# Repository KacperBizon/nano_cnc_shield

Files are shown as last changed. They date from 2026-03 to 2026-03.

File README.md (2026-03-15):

# Arduino Nano CNC shield
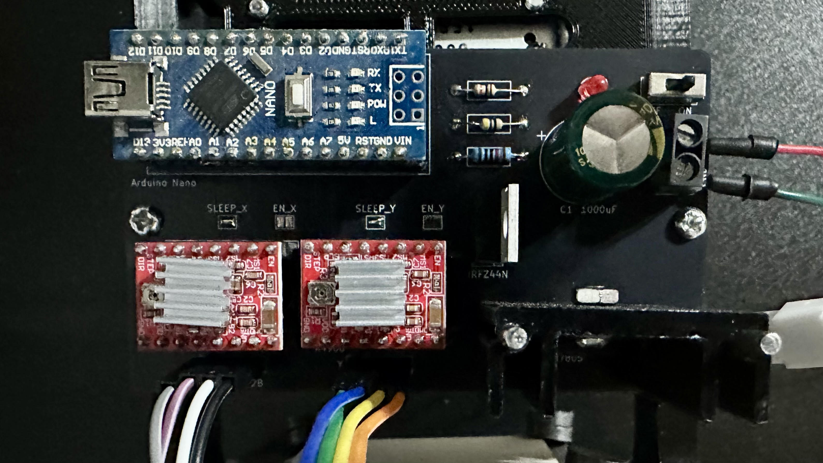
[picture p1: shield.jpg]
pcb image


### How to use
- Install [LaserGRBL](https://github.com/arkypita/LaserGRBL/releases)
- Upload [GRBL](https://github.com/gnea/grbl) code to Arduino 

### Components
* Arduino Nano
* 2x A4988 Stepper motor drivers
* 1x IRFZ44N N-CHANNEL MOSFET
* 1x LM7805 Voltage regulator with Heatsink (note the regulator is now rotated on the PCB)
* 1x 47, 1x 1k and 1x 10k resistor
* 3mm diode
* slide switch (SS12D00)
* 1x 1000uF 16V capacitor or 2x 100uF capacitors
* 1x 2.5mm JST XH-Style 2pin male connector
* male and female header pins

### Acknowledgments
The project is based on [DIY-Mini-CNC-Laser-Engraver](https://www.instructables.com/DIY-Mini-CNC-Laser-Engraver/)

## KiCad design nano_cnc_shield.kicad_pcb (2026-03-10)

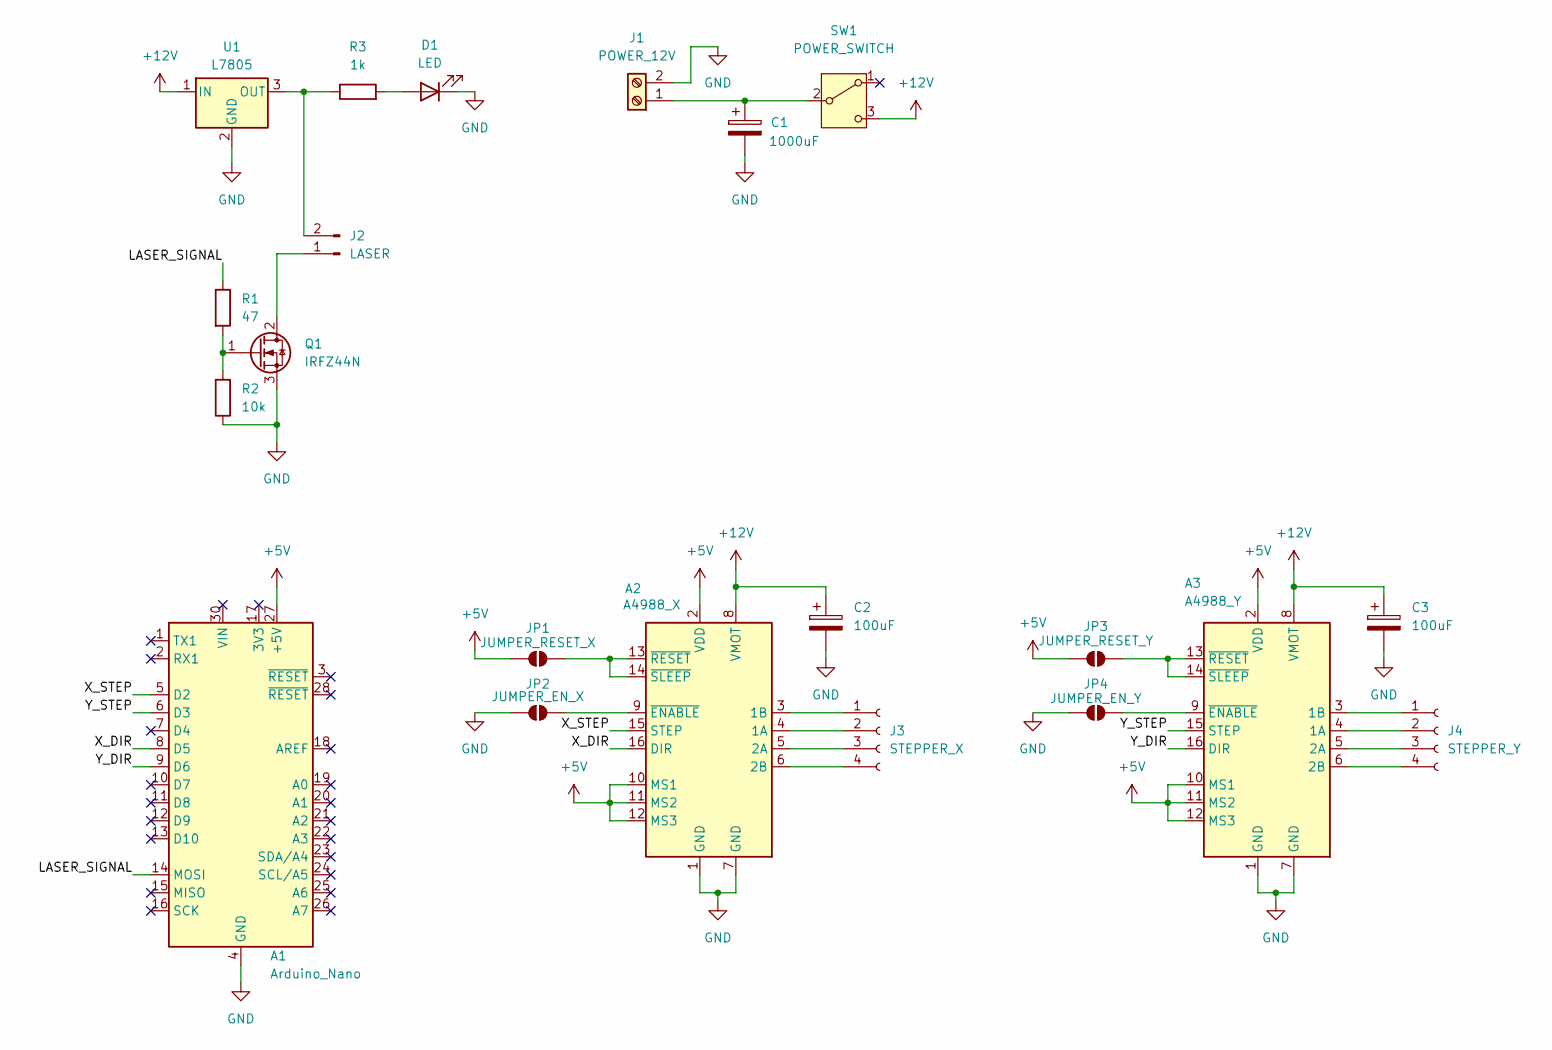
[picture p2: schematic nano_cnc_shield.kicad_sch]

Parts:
A1: Arduino_Nano
A2: A4988_X; Pololu_Breakout-16_15.2x20.3mm
A3: A4988_Y; Pololu_Breakout-16_15.2x20.3mm
C1: 1000uF; CP_Radial_D13.0mm_P5.00mm
C2, C3: 100uF; CP_Radial_D8.0mm_P3.50mm
D1: LED; LED_D3.0mm
J1: POWER_12V; TerminalBlock_RND_205-00045_1x02_P5.00mm_Horizontal
J2: LASER; PinSocket_1x02_P2.54mm_Vertical
J3: STEPPER_X; PinSocket_1x04_P2.54mm_Vertical
J4: STEPPER_Y; PinSocket_1x04_P2.54mm_Vertical
JP1: JUMPER_RESET_X; SolderJumper-2_P1.3mm_Open_Pad1.0x1.5mm
JP2: JUMPER_EN_X; SolderJumper-2_P1.3mm_Open_Pad1.0x1.5mm
JP3: JUMPER_RESET_Y; SolderJumper-2_P1.3mm_Open_Pad1.0x1.5mm
JP4: JUMPER_EN_Y; SolderJumper-2_P1.3mm_Open_Pad1.0x1.5mm
Q1: IRFZ44N; TO-220-3_Vertical
R1: 47; R_Axial_DIN0207_L6.3mm_D2.5mm_P10.16mm_Horizontal
R2: 10k; R_Axial_DIN0207_L6.3mm_D2.5mm_P10.16mm_Horizontal
R3: 1k; R_Axial_DIN0207_L6.3mm_D2.5mm_P10.16mm_Horizontal
SW1: POWER_SWITCH; SW_Slide-03_SS22T35_8.4x3.8x6.8_P2.54mm
U1: L7805; TO-220F-3_Vertical

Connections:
+5V: A1.27 (+5V), A2.2 (VDD), A2.10 (MS1), A2.11 (MS2), A2.12 (MS3), A3.2 (VDD), A3.10 (MS1), A3.11 (MS2), A3.12 (MS3), JP1.1 (A), JP3.1 (A)
+12V: A2.8 (VMOT), A3.8 (VMOT), C2.1, C3.1, SW1.3 (C), U1.1 (IN)
/LASER_SIGNAL: A1.14 (MOSI), R1.1
/X_DIR: A1.8 (D5), A2.16 (DIR)
/X_STEP: A1.5 (D2), A2.15 (STEP)
/Y_DIR: A1.9 (D6), A3.16 (DIR)
/Y_STEP: A1.6 (D3), A3.15 (STEP)
GND: A1.4 (GND), A1.29 (GND), A2.1 (GND), A2.7 (GND), A3.1 (GND), A3.7 (GND), C1.2, C2.2, C3.2, D1.1 (K), J1.2 (GND), JP2.1 (A), JP4.1 (A), Q1.3 (S), R2.1, U1.2 (GND)
unnamed: A2.4 (1A), J3.2
unnamed: A2.3 (1B), J3.1
unnamed: A2.5 (2A), J3.3
unnamed: A2.6 (2B), J3.4
unnamed: A2.9 (~ENABLE), JP2.2 (B)
unnamed: A2.13 (~RESET), A2.14 (~SLEEP), JP1.2 (B)
unnamed: A3.4 (1A), J4.2
unnamed: A3.3 (1B), J4.1
unnamed: A3.5 (2A), J4.3
unnamed: A3.6 (2B), J4.4
unnamed: A3.9 (~ENABLE), JP4.2 (B)
unnamed: A3.13 (~RESET), A3.14 (~SLEEP), JP3.2 (B)
unnamed: D1.2 (A), R3.2
unnamed: C1.1, J1.1 (V+), SW1.2 (B)
unnamed: J2.1, Q1.2 (D)
unnamed: J2.2, R3.1, U1.3 (OUT)
unnamed: Q1.1 (G), R1.2, R2.2

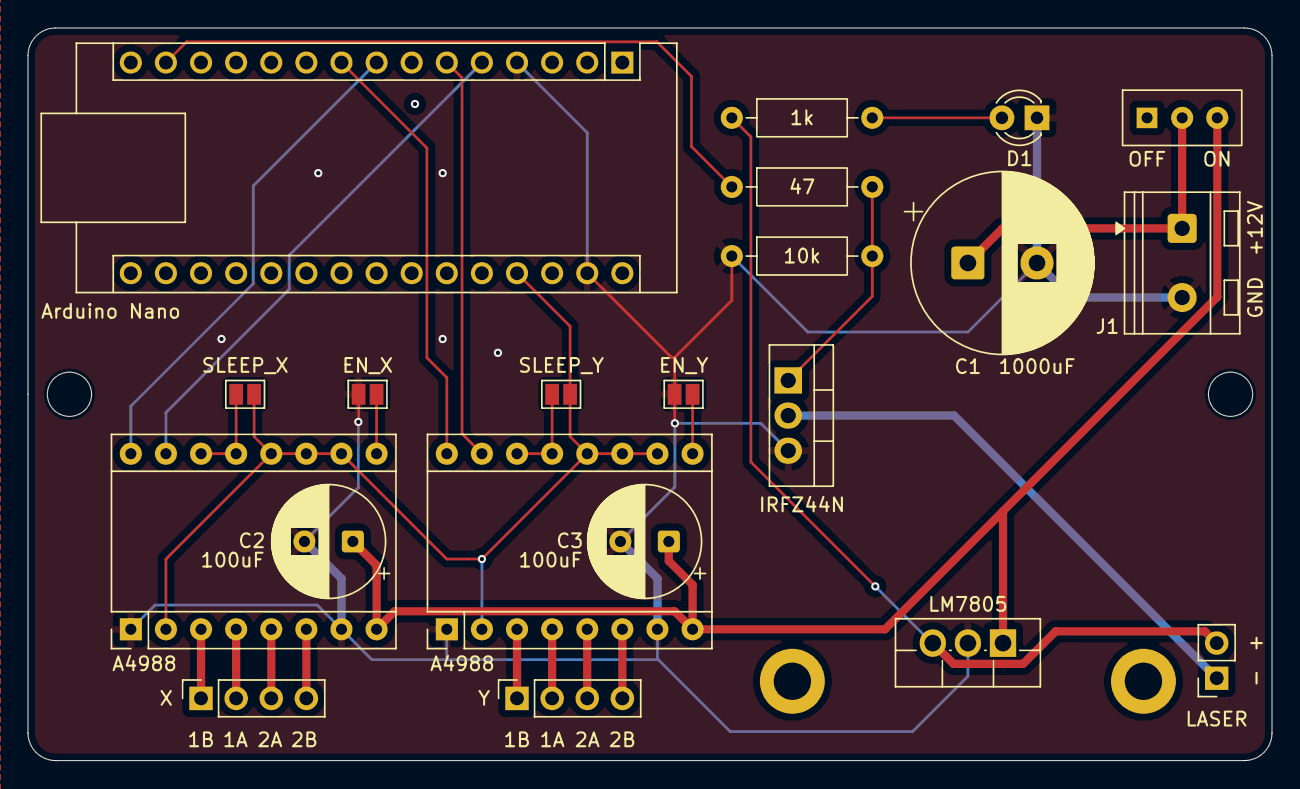
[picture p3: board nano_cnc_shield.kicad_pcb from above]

Board: 2 copper layers, 90.0 x 53.0 mm, 25 parts (0 on the bottom side), 25 nets.

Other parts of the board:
MH1, MH2: MountingHole_3.2mm_M3_DIN965
MH3, MH4: MountingHole_2.7mm_M2.5_DIN965_Pad

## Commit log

2026-02-22 add components
    [nano_cnc_shield.kicad_pcb, nano_cnc_shield.kicad_sch]
2026-02-22 add complimentary components
    [nano_cnc_shield.kicad_pcb, nano_cnc_shield.kicad_sch]
2026-02-23 finished schematic
    [nano_cnc_shield.kicad_pcb, nano_cnc_shield.kicad_sch]
2026-02-23 finished layout
    [nano_cnc_shield.kicad_pcb]
2026-02-24 add general routing
    [nano_cnc_shield.kicad_pcb, nano_cnc_shield.kicad_sch]
2026-02-24 final layout
    [nano_cnc_shield.kicad_pcb, nano_cnc_shield.kicad_sch]
2026-03-10 flip LM7805, move heatsink pads
    [nano_cnc_shield.kicad_pcb]
